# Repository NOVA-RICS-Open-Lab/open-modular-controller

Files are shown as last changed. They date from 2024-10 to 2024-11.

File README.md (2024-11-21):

<div  align="center"> 

# Open Modular Controller for Automation Technologies




[Joao Potier](https://pt.linkedin.com/in/jo%C3%A3o-potier-5b1301228?trk=public_profile_samename-profile)<sup>1</sup>, 
[Miguel Arvana](https://scholar.google.com/citations?user=UBvr388AAAAJ&hl=pt-PT)<sup>1</sup>,
[Leandro Filipe](https://scholar.google.pt/citations?user=SoIohJwAAAAJ&hl=en)<sup>1</sup>,
[Fabio M-Oliveira](https://www.researchgate.net/profile/Fabio-M-Oliveira)<sup>1</sup>,
[Andre Rocha](https://scholar.google.pt/citations?user=k1GIyqcAAAAJ&hl=pt-PT)<sup>1</sup>,
[Jose Barata](https://scholar.google.pt/citations?user=4G8tKCsAAAAJ&hl=en)<sup>1</sup>

<sup>1</sup> **NOVA School of Science and Technology, Center of Technology and Systems (UNINOVA-CTS)**,
and Associated Lab of Intelligent Systems (LASI), NOVA University
Lisbon, 2829-516 Lisbon, Portugal

<table>
  <tr>
    <td style="vertical-align: top;">
      This work proposes the development of a controller, with modularity and flexibility as the core ideas, that allows for the integration of open-source standards like the proprietary technologies used in emergent factories and automation technologies. The implementation of this architecture led to the development of a prototype modular industrial controller that is, on average, a quarter of the cost of the new generation of industrial controllers. The developed controller was tested and validated using some educational kits.
    </td>
    <td style="vertical-align: top;">
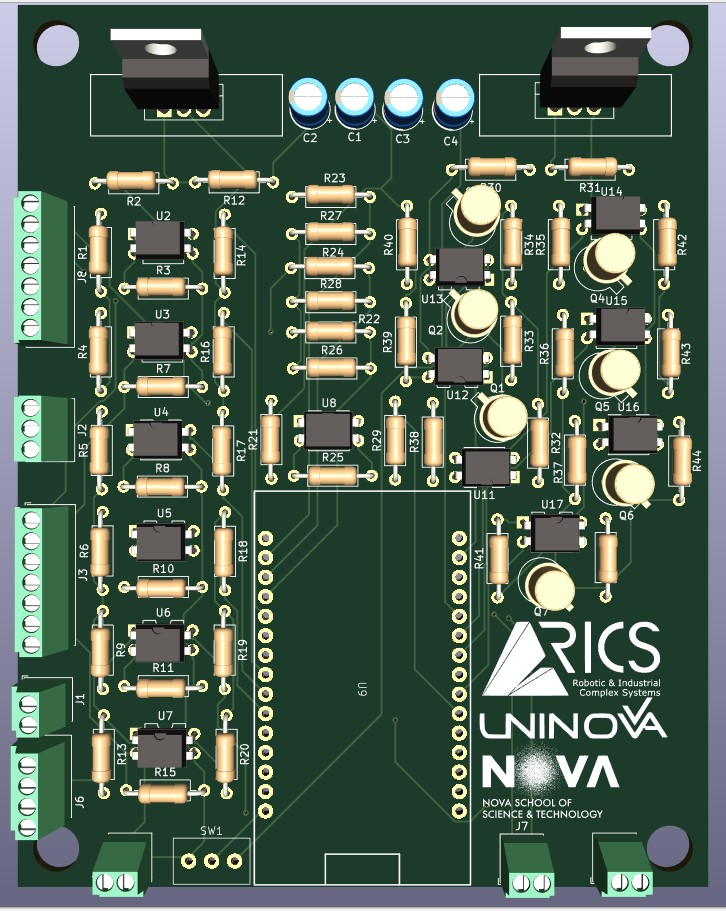
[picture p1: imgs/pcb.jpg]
pcb
      
    </td>
  </tr>
</table>

</div>

## <div align="center">Get Started</div>
Follow these steps to create your own functional PCB and set up the ESP:

1. **Order or Print the PCB**
   - Locate the PCB Gerber files in the repository at [Gerber.zip](./docs/pcb/Gerbers.zip).
   - Upload this zip file to a PCB manufacturer (such as [JLCPCB](https://jlcpcb.com/) or a similar service) to order the PCB, or print it yourself if you have access to the necessary equipment.

2. **Gather Components**
   - Obtain all components listed in [materials.xlsx](./docs/pcb/materials.xlsx).
   - Ensure that you source parts that match the specifications provided for optimal functionality.

3. **Assemble the PCB**
   - Carefully assemble the PCB following the schematic available [here](./imgs/schematic.png).
   - Use appropriate tools and ensure correct orientation and placement of components.

4. **Test the PCB**
   - Before powering up, inspect the PCB for short circuits, weak solder joints, or other assembly issues.
   - Use a multimeter to verify connections and confirm proper voltage levels across components.

5. **Program and Test the ESP**
   - Program the ESP with the provided code, following the libraries in the [src/libs](./src/libs) folder. Test your assembled controller and code setup with this short [example](./src/protoboardValid.ino).
   - Test each pin individually to verify its input and output behavior. The ESP should handle a standard 24V input/output.

If all tests pass, congratulations! Your board is now ready for operation.

---

### Usage instructions
Once your PCB and ESP setup is complete, you can begin using the device. The ESP manages the input and output for each control pin, with a standard operating voltage of 24V. Please note:

- **Control Limitations**: These pins are designed for control signals only. Avoid applying high current loads to prevent damage.
- **Testing & Example Code**: Refer to the [tests](./tests/) folder for use case examples and tests that helped validate board functionality. This includes the protoboard validation, Wi-Fi connection, Web Server and IP connection.

Follow these guidelines, and your project should operate as expected!

---

### Project Structure
For you to better understand this repository organization here is a quick overview of its structure and where to find what you might be looking for:
```
open-modular-controller
├── docs                # documentation assets
│   ├── circuits            # digital and analog circuit study
│   ├── pcb                 # pcb assets and materials
│   └── thesis.pdf          # master thesis
├── imgs                # images from this project
├── src                 # evaluation code
│   ├── libs                # developed libraries
│   └── protoboardValid.ino         # validation circuit
└── tests               # use case example scripts
```

## <div align="center">Documentation</div>
The [docs](./docs/) directory contains extensive resources, including schematics, materials lists, and PCB files, as well as the original master’s dissertation that inspired this project. Explore this folder to access all necessary assets for building, assembling, and understanding the hardware.

The presented use case for the protoboard validation showcases an asynchronous Web Server, providing a more stable connection than a synchronous web server. A toggle switch sends an HTTP request to the Processing Unit Module, initiating movement in the Kit. When the switch is active, it enables continuous operation of the Kit's process. Upon deactivation, the Industrial Kit halts movement at the start of the next cycle.

> **Note**: The resistors R1, R4, R5, R6, R9, R13, and R21, **originally specified as 1.1K, have been updated to 33K** in both the schematic and materials list. This adjustment was made due to performance issues with certain conveyor belts that were not functional with the previous resistor values. Documenting this change is essential for any future debugging.

## <div align="center">Contribution Guidelines</div>
NOVA RICS Open Lab open source, and we welcome contributions from the community! See the [Contribution](CONTRIBUTING.md) guide for more information on the development workflow and the internals of the wandb library. For project related bugs and feature requests, visit [GitHub Issues](https://github.com/NOVA-RICS-Open-Lab/open-modular-controller/issues) or contact novaricsopenlab@gmail.com

## <div align="center">Citation</div>
If you use or intend to build on top of  the work in this repo, please consider citing our project:
```bibtex
@inproceedings{10639979,
  author={Potier, João and Arvana, Miguel and Filipe, Leandro and M-Oliveira, Fabio and Rocha, Andre Dionisio and Barata, Jose},
  booktitle={2024 IEEE 7th International Conference on Industrial Cyber-Physical Systems (ICPS)}, 
  title={Development of an Open, Modular Controller for Training in Emergent Automation Technologies}, 
  year={2024},
  doi={10.1109/ICPS59941.2024.10639979}
}
```

## <div align="center">License</div>
This repository is released under the MIT License. Please see the [LICENSE](LICENSE) file for more details.

## <div align="center">Contacts</div>
For any questions regarding this or any other project please contact us at novaricsopenlab@gmail.com or enroll in our [Discussion Forum](https://github.com/NOVA-RICS-Open-Lab/open-modular-controller/discussions) for sharing your ideas and sharing projects.

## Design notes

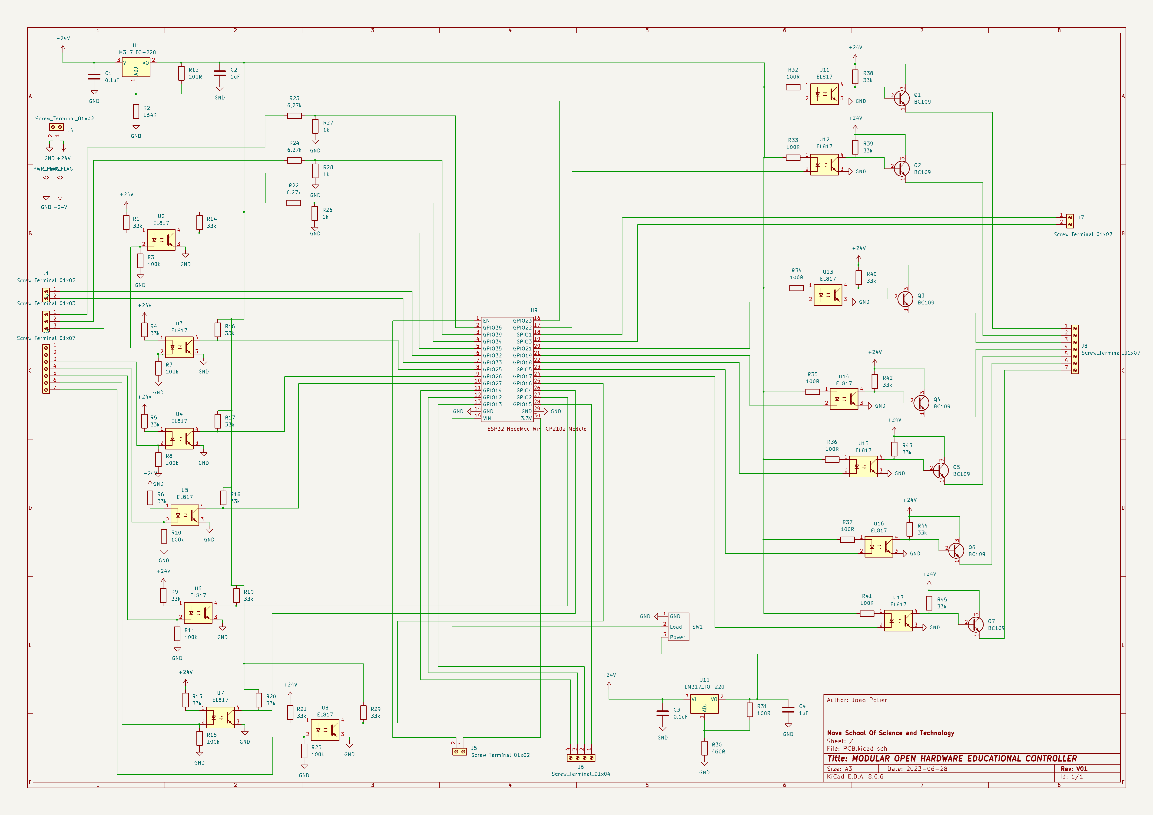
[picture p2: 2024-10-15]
imgs/schematic.png

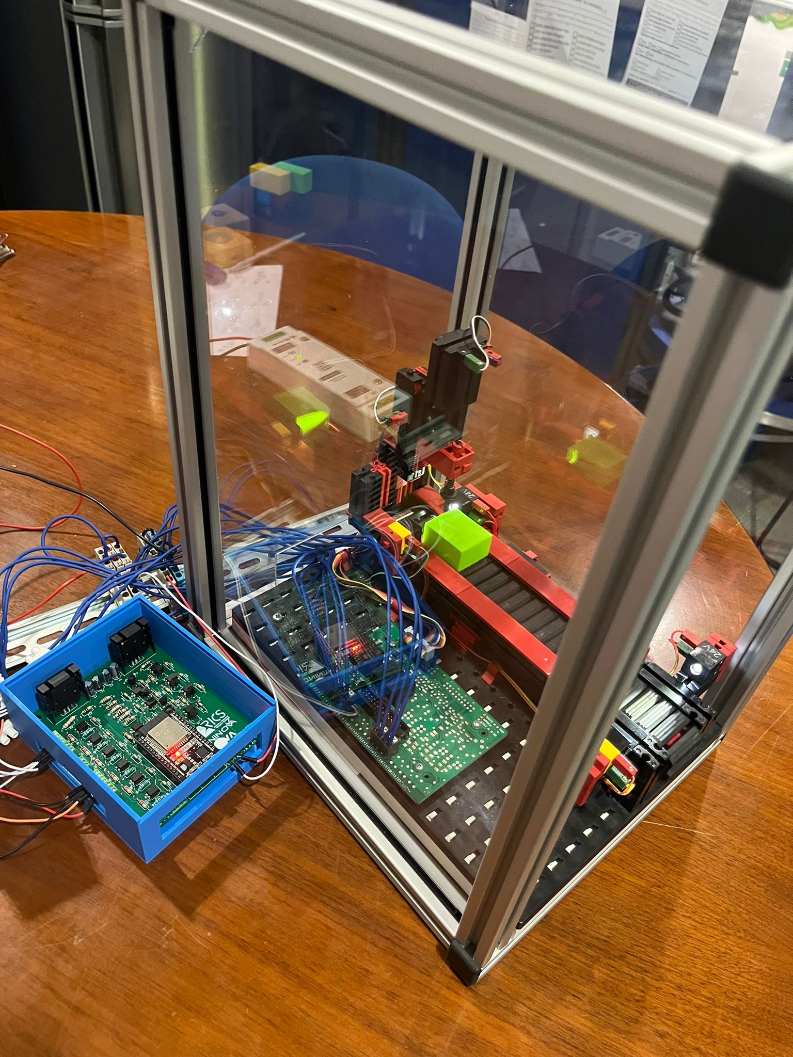
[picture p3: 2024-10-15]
imgs/use_case.jpg

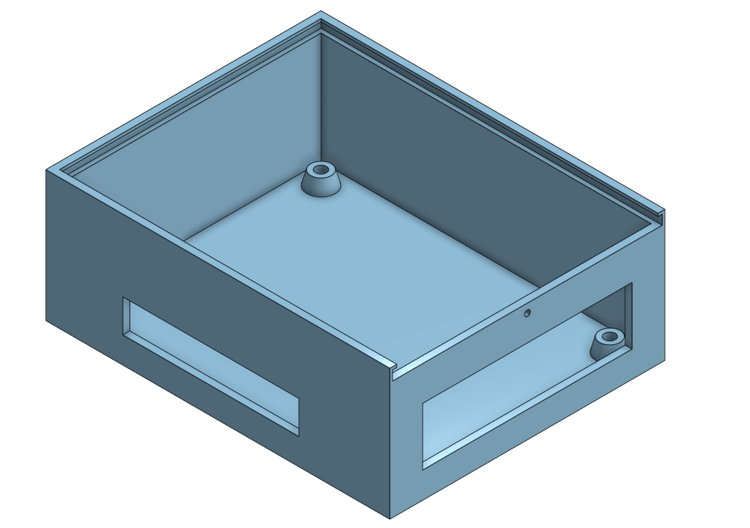
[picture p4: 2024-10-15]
imgs/3d_box.png

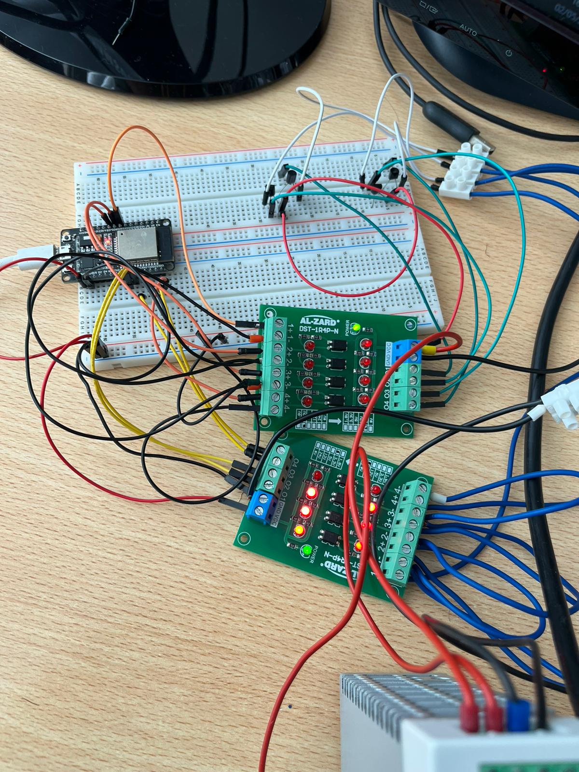
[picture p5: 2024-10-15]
imgs/sensors_actuators.jpg

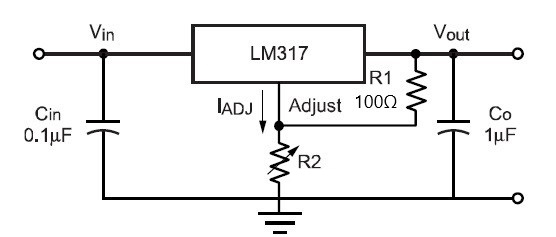
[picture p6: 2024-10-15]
docs/circuits/LM317Circuit.jpg

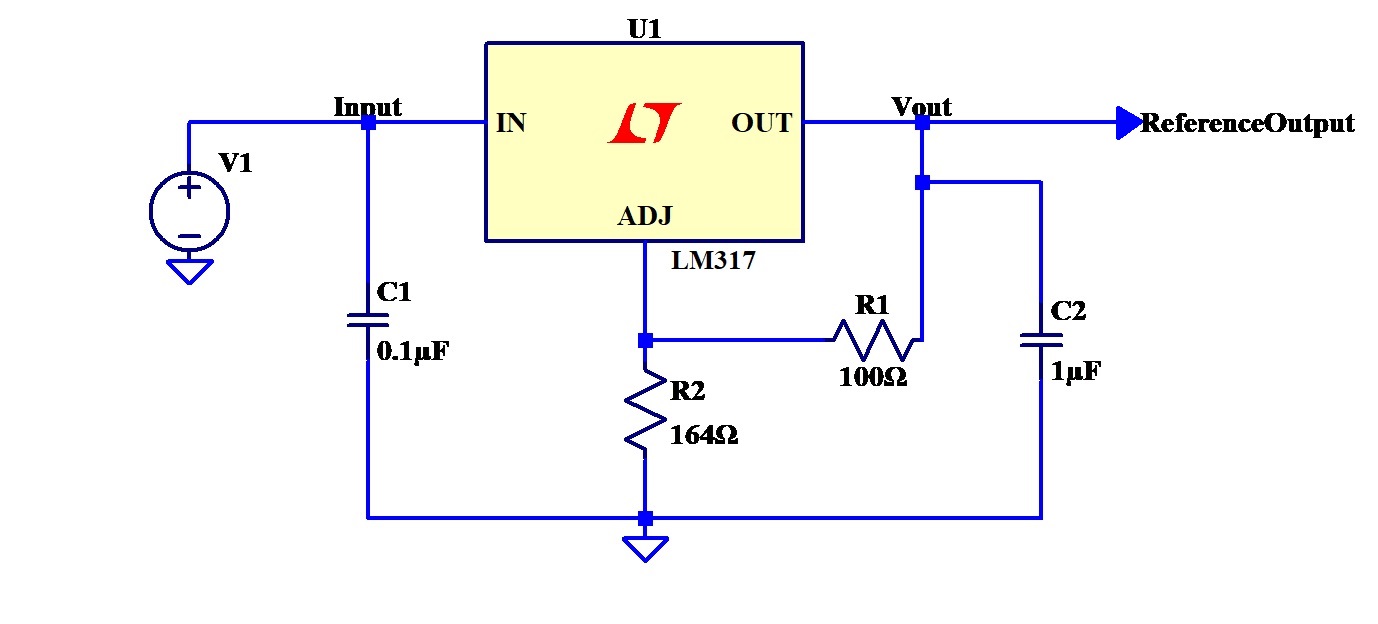
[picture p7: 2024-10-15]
docs/circuits/LM317Circuit_33V.jpg

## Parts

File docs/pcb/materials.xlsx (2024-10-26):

Quantity | Value | LibPart | Footprint | Link | Notes
2 | 1uF | Capacitor | Capacitor_THT:CP_Radial_D5.0mm_P2.00mm | https://mauser.pt/catalog/product_info.php?products_id=004-0013
2 | 0,1uF | Capacitor | Capacitor_THT:CP_Radial_D5.0mm_P2.00mm | https://mauser.pt/catalog/product_info.php?products_id=004-0001
0 | 1,1k | Resistor | Resistor_THT:R_Axial_DIN0207_L6.3mm_D2.5mm_P10.16mm_Horizontal | https://mauser.pt/catalog/product_info.php?products_id=104-7459 | Não existem resistências destas. As de 1,2K funcionam/// Foram subestituidas por 33K
7 | 100k | Resistor | Resistor_THT:R_Axial_DIN0207_L6.3mm_D2.5mm_P10.16mm_Horizontal | https://mauser.pt/catalog/product_info.php?products_id=104-7060
9 | 100R | Resistor | Resistor_THT:R_Axial_DIN0207_L6.3mm_D2.5mm_P10.16mm_Horizontal | https://mauser.pt/catalog/product_info.php?products_id=104-7358
1 | 164R | Resistor | Resistor_THT:R_Axial_DIN0207_L6.3mm_D2.5mm_P10.16mm_Horizontal | https://mauser.pt/catalog/product_info.php?products_id=104-7478 | Não existem resistências destas. As de 150 funcionam
3 | 1k | Resistor | Resistor_THT:R_Axial_DIN0207_L6.3mm_D2.5mm_P10.16mm_Horizontal | https://mauser.pt/catalog/product_info.php?products_id=104-7597
21 | 33k | Resistor | Resistor_THT:R_Axial_DIN0207_L6.3mm_D2.5mm_P10.16mm_Horizontal | https://mauser.pt/catalog/product_info.php?products_id=104-7794
1 | 460R | Resistor | Resistor_THT:R_Axial_DIN0207_L6.3mm_D2.5mm_P10.16mm_Horizontal |  | Não existem resistências destas. As de 470 funcionam
3 | 6,27k | Resistor | Resistor_THT:R_Axial_DIN0207_L6.3mm_D2.5mm_P10.16mm_Horizontal | https://mauser.pt/catalog/product_info.php?products_id=104-7668 | Não existem resistências destas. As de 6,2K funcionam
7 | BC547 | Transistor_BJT | Package_TO_SOT_THT:TO-18-3 | https://mauser.pt/catalog/product_info.php?products_id=002-0243
14 | EL817 | Isolator | Package_DIP:DIP-4_W7.62mm | https://mauser.pt/catalog/product_info.php?products_id=002-1805
2 | LM317_TO-220 | Regulator_Linear | Package_TO_SOT_THT:TO-220-3_Vertical | https://mauser.pt/catalog/product_info.php?products_id=001-9061
3 | Screw_Terminal_01x02 | Connector | TerminalBlock_Phoenix:TerminalBlock_Phoenix_MPT-0,5-2-2.54_1x02_P2.54mm_Horizontal | https://mauser.pt/catalog/product_info.php?products_id=011-1612
1 | Screw_Terminal_01x03 | Connector | TerminalBlock_Phoenix:TerminalBlock_Phoenix_MPT-0,5-3-2.54_1x03_P2.54mm_Horizontal | https://mauser.pt/catalog/product_info.php?products_id=011-2824
1 | Screw_Terminal_01x04 | Connector | TerminalBlock_Phoenix:TerminalBlock_Phoenix_MPT-0,5-4-2.54_1x04_P2.54mm_Horizontal | https://mauser.pt/catalog/product_info.php?products_id=011-2825
2 | Screw_Terminal_01x07 | Connector | TerminalBlock_Phoenix:TerminalBlock_Phoenix_MPT-0,5-7-2.54_1x07_P2.54mm_Horizontal |  | Combinar um bloco de 3 com um bloco de 4

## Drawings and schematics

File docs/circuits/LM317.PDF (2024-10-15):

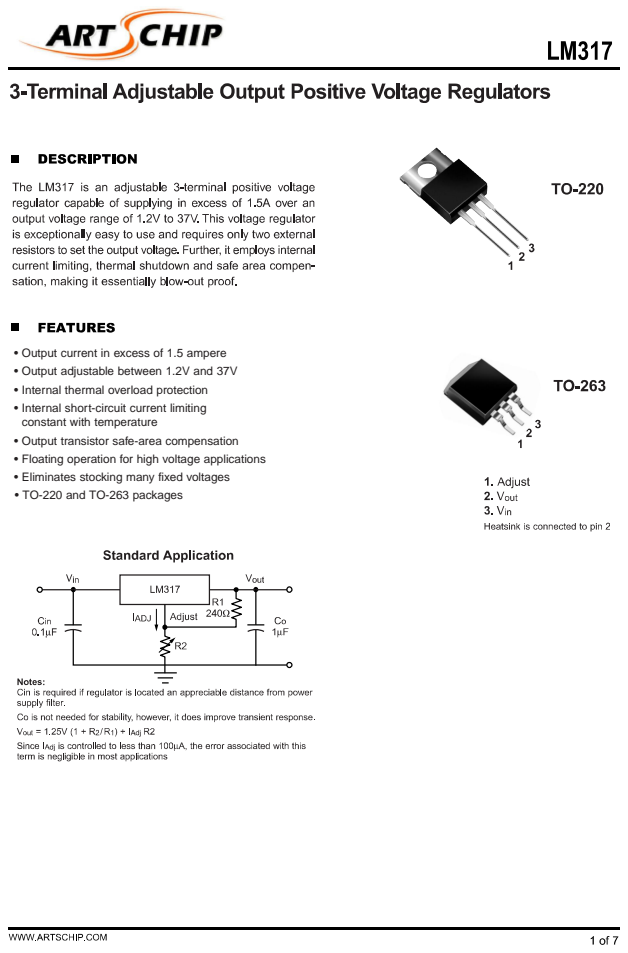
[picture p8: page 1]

• Output current in excess of 1.5 ampere
• Output adjustable between 1.2V and 37V
• Internal thermal overload protection
• Internal short-circuit current limiting
constant with temperature
• Output transistor safe-area compensation
• Floating operation for high voltage applications
• Eliminates stocking many fixed voltages
• TO-220 and TO-263 packages

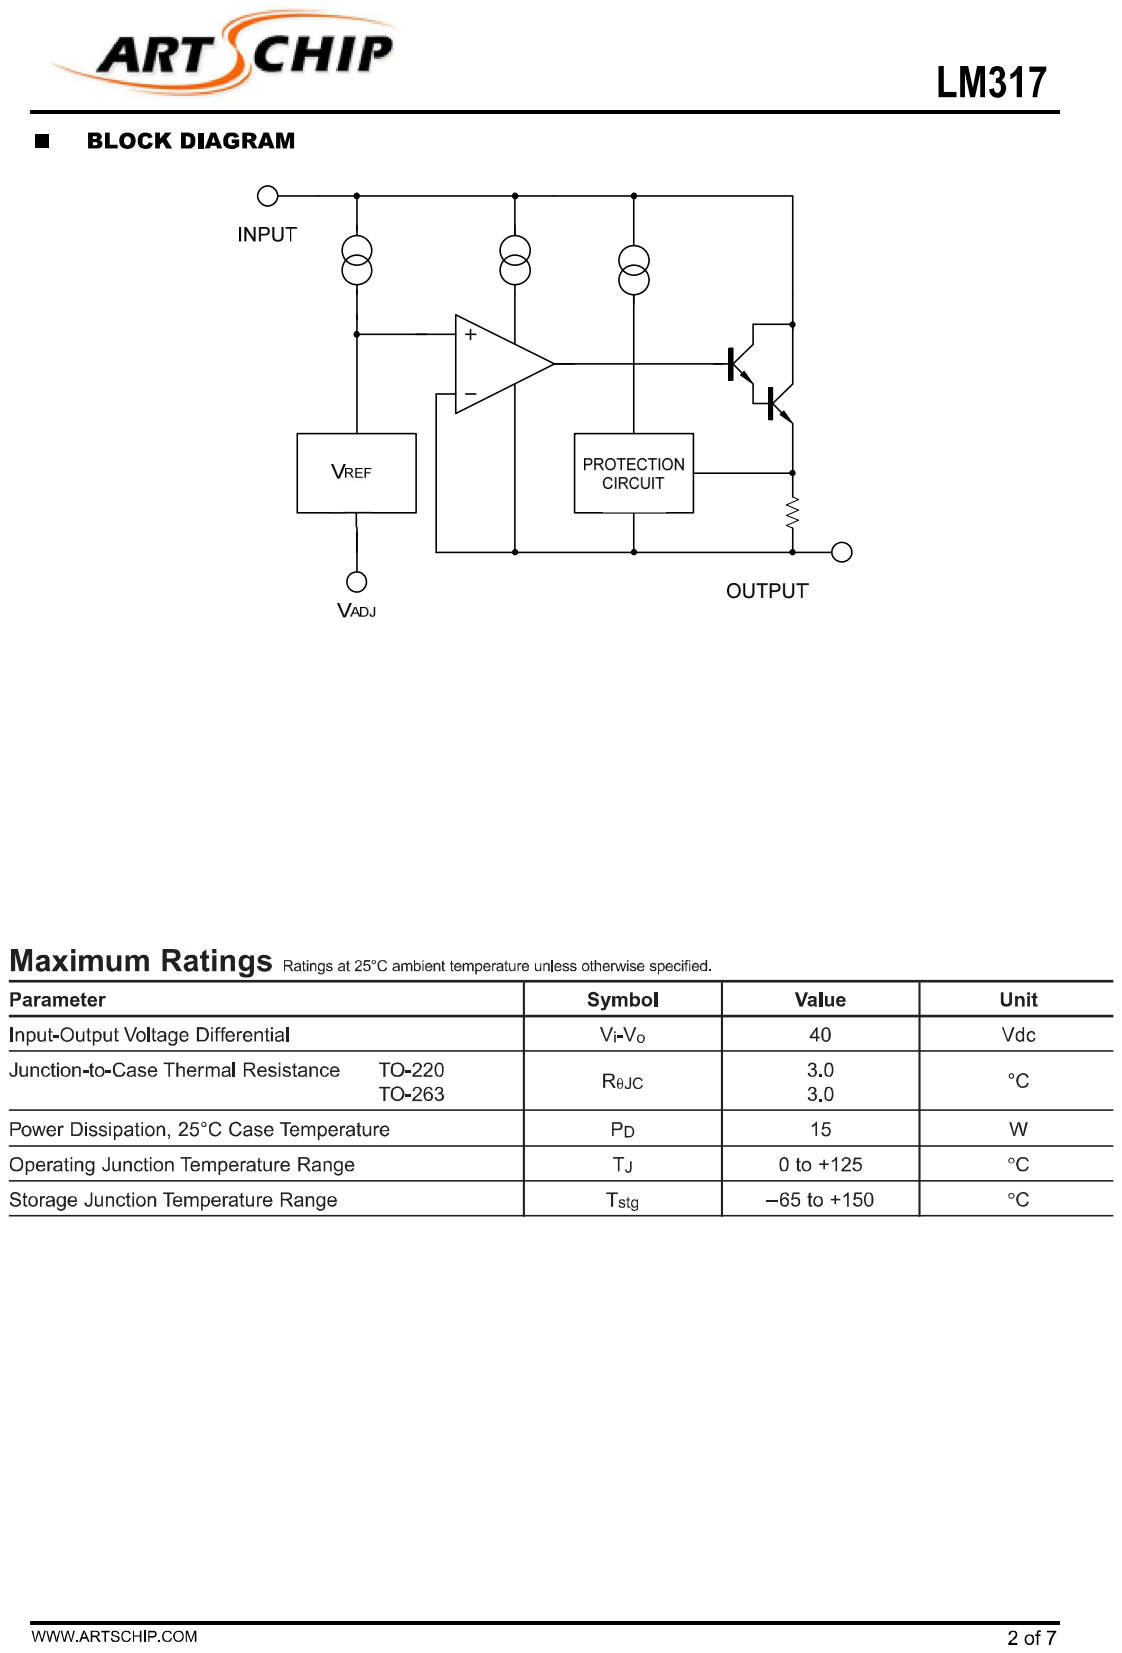
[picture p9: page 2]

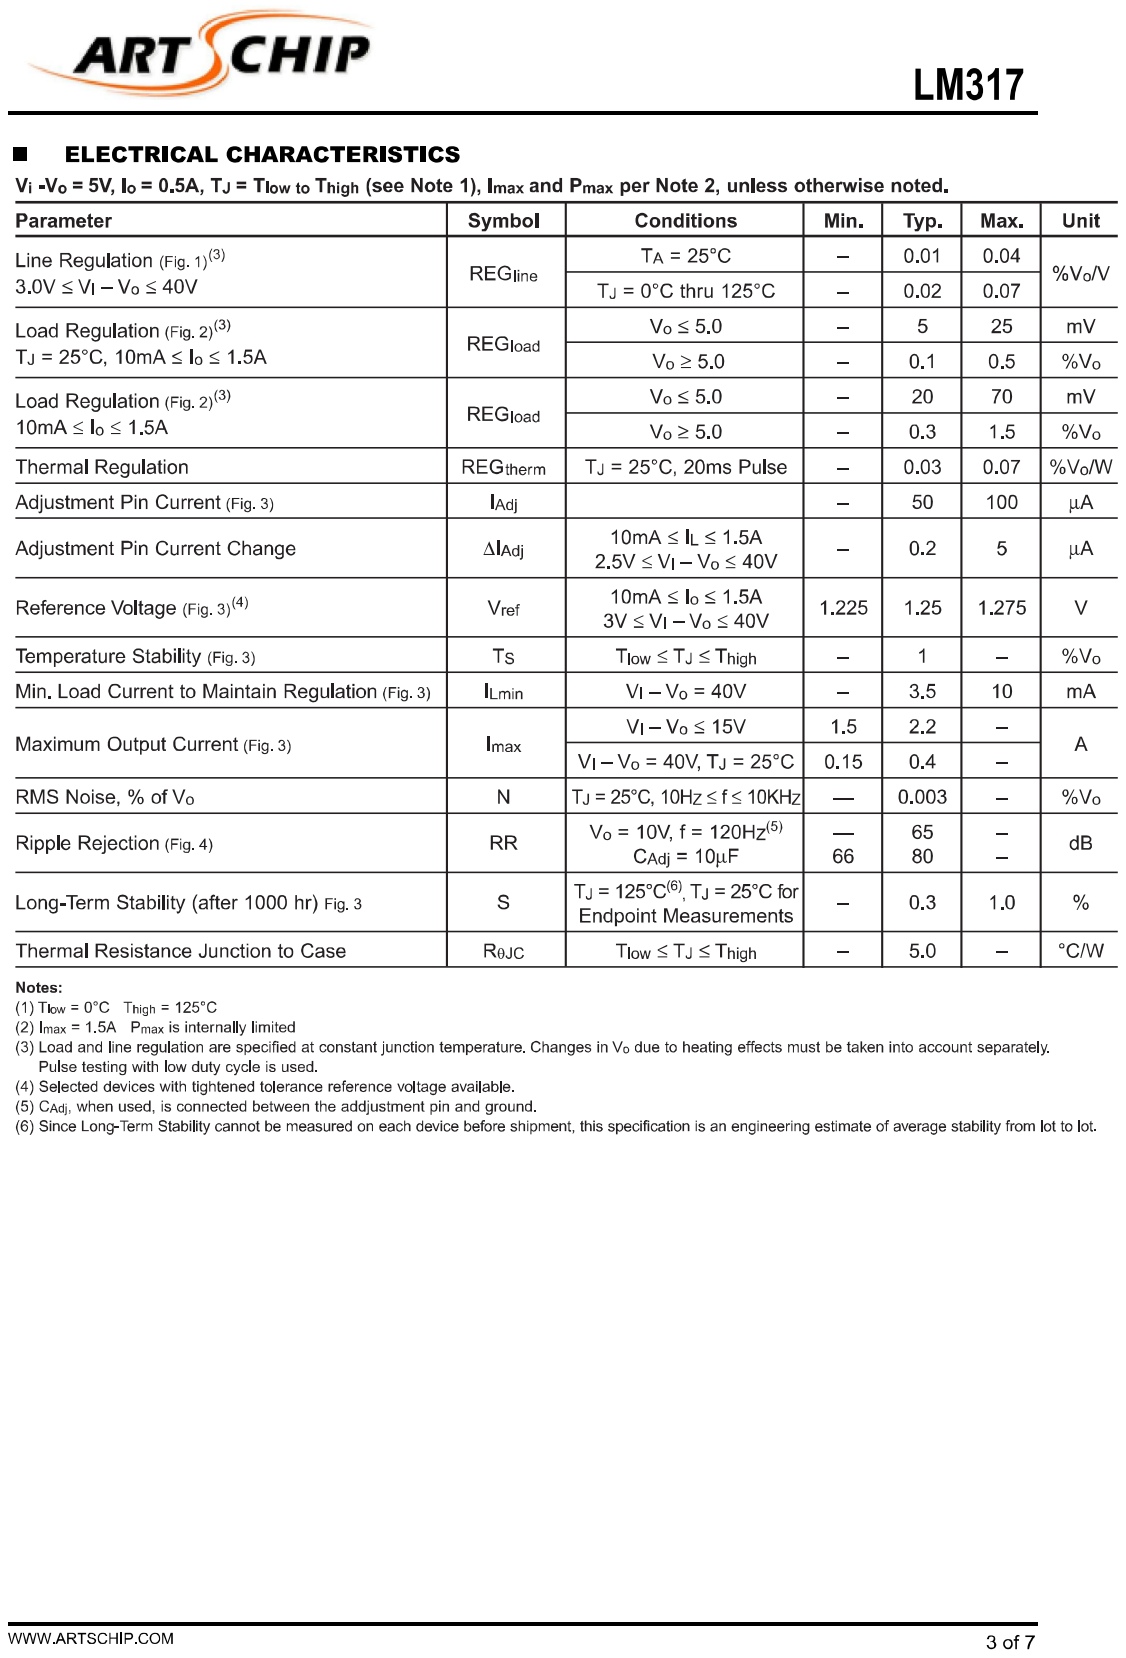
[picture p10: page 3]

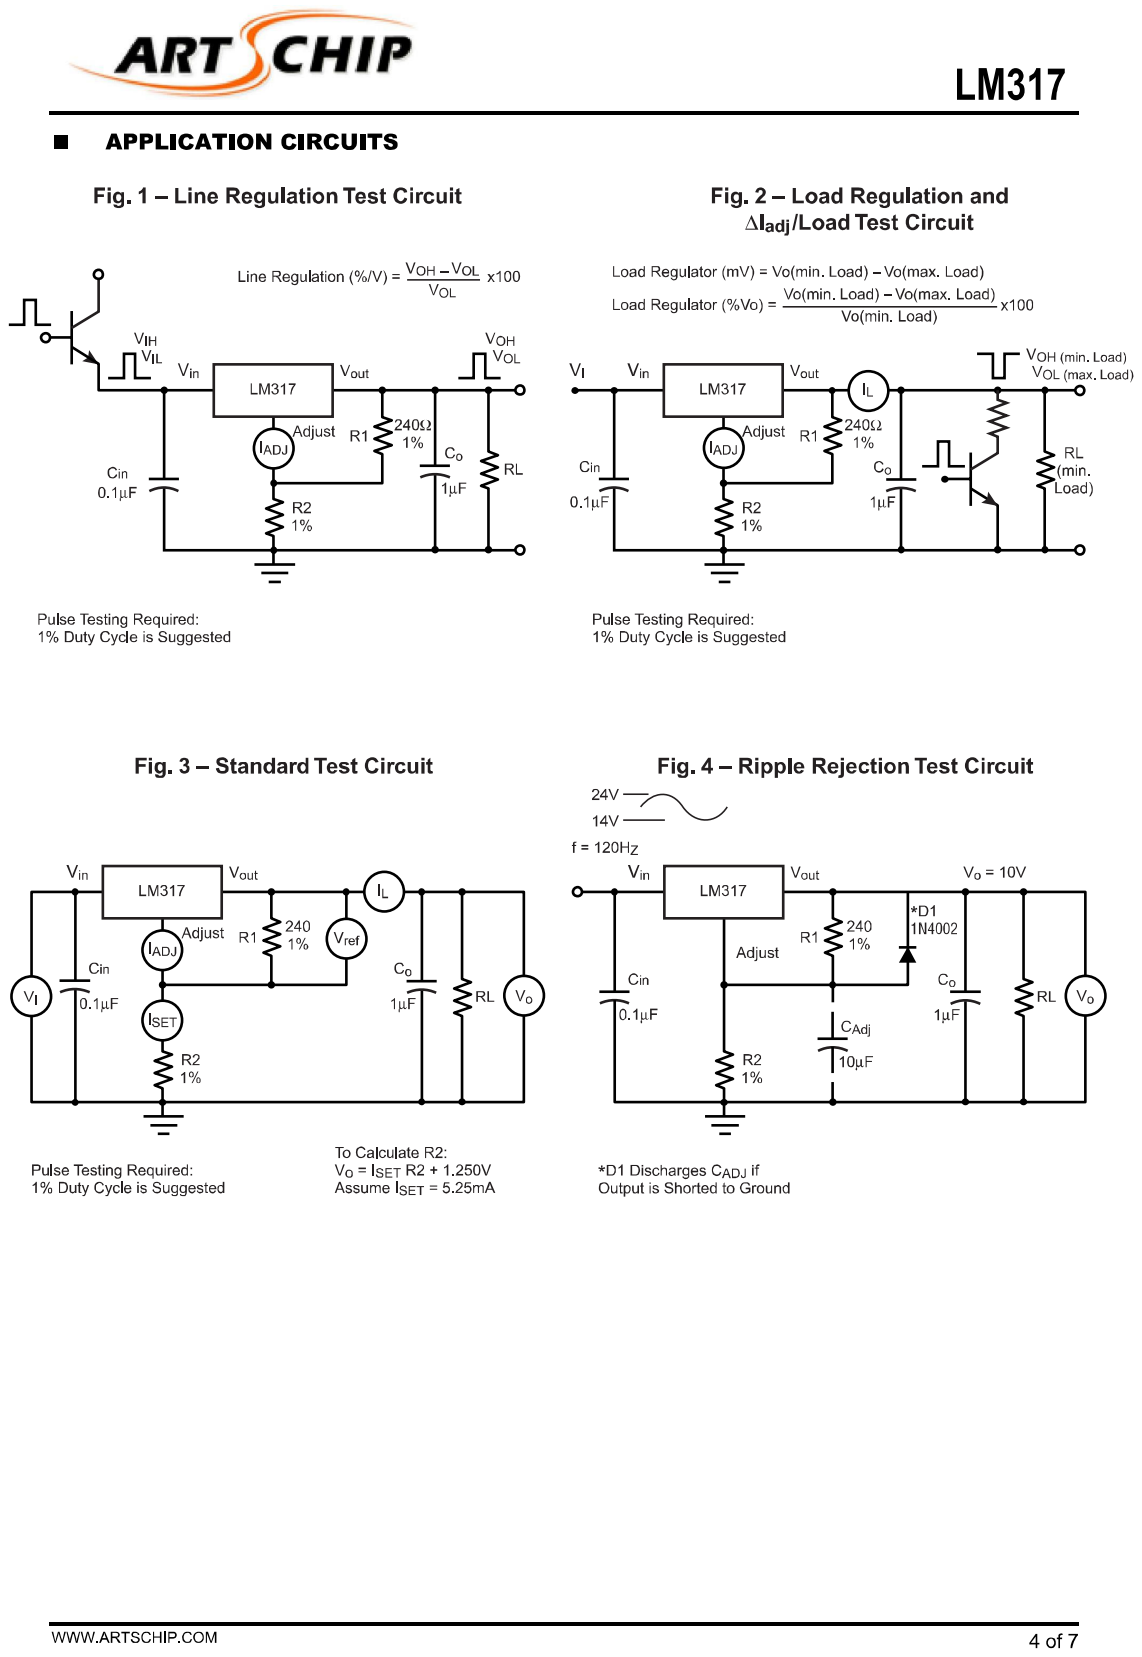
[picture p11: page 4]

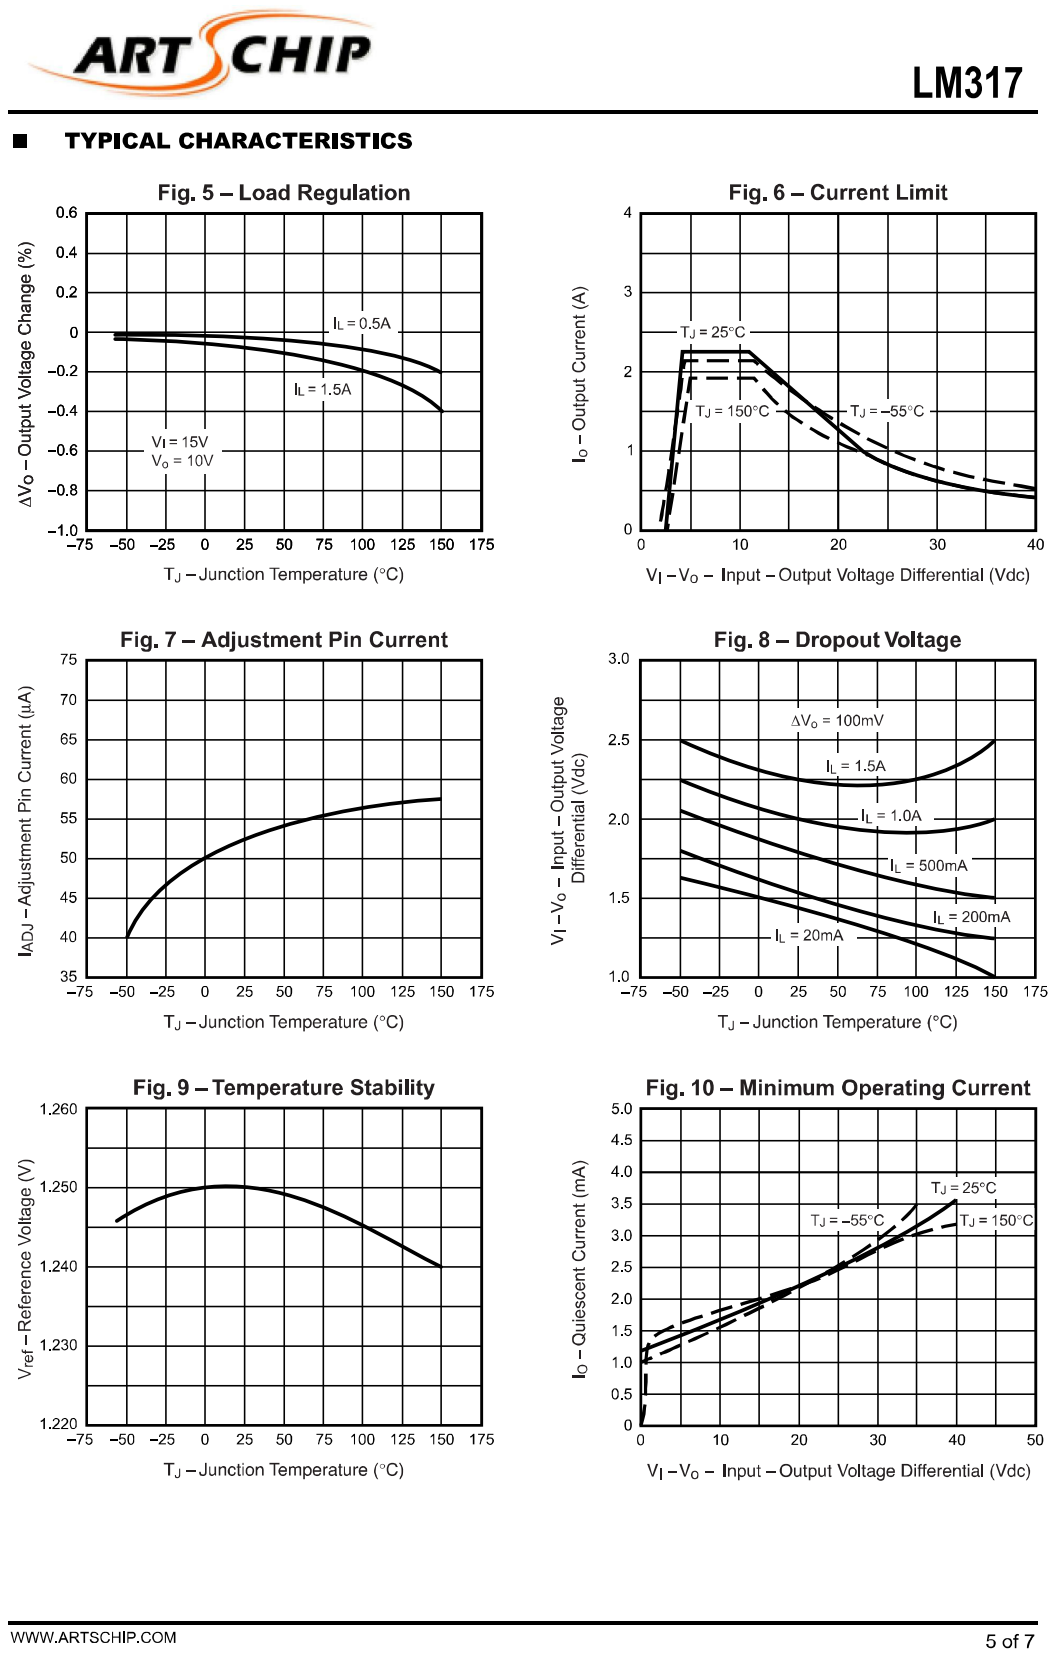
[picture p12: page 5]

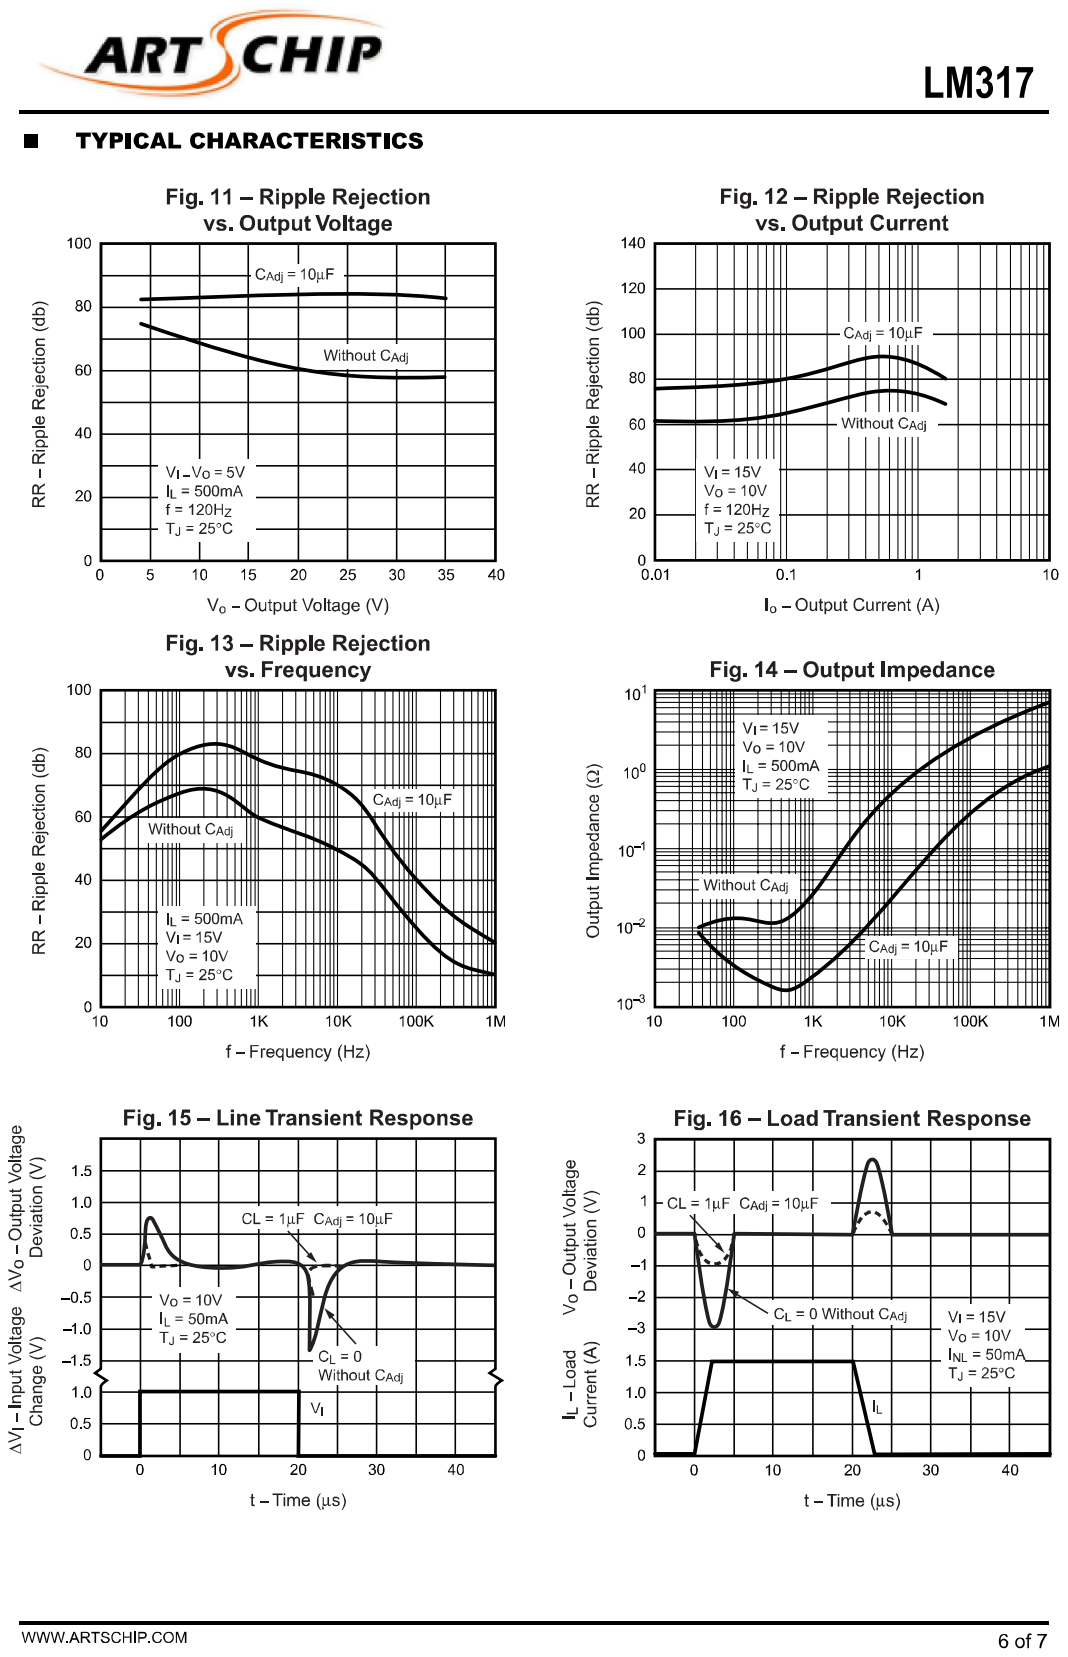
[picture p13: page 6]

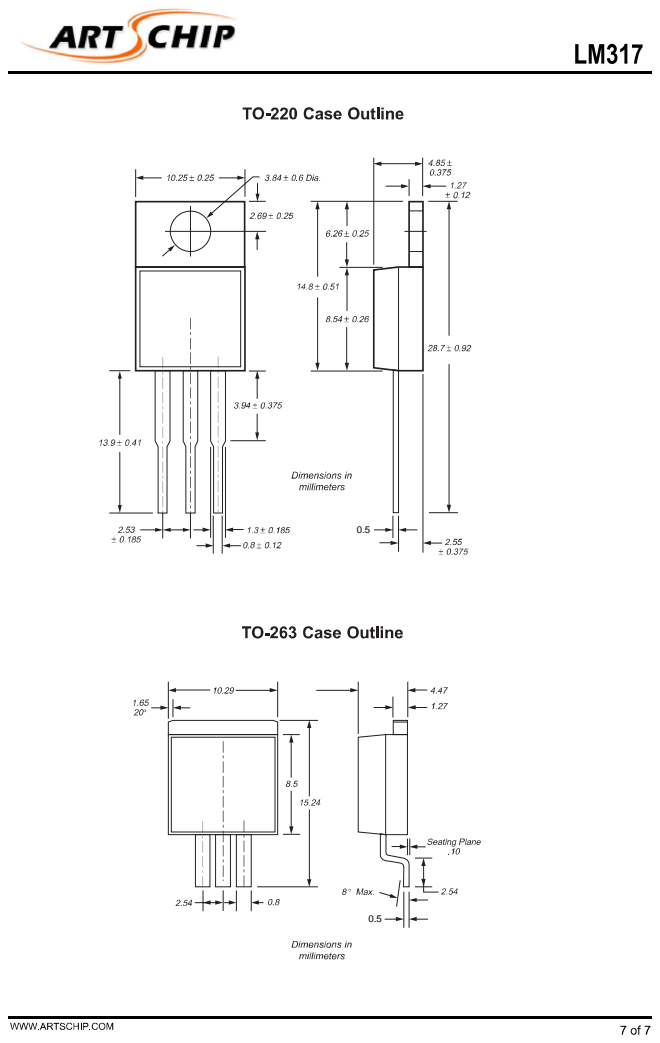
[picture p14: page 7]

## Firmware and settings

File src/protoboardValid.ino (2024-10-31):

#include "protoboardLib.h"

Node node = Node();
int in1, in2;

void setup() {
  node.initDigitalInput("I6");
  Serial.begin(9600);
}


void loop() {
  in2 = node.readDigitalPort("I6");
  Serial.write("->");

  if(in2 == LOW){
    Serial.write("Sensor 2 not active\n");
  }

  if(in2 == HIGH){
    Serial.write("Sensor 2 is active\n");
      
  } 
  delay(5000);
}

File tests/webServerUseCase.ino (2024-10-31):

#include <WiFi.h>
#include <AsyncTCP.h>
#include <ESPAsyncWebServer.h>
#include "protoboardLib.h"
#include "useCaseKitLib.h"

// Replace with your network credentials
const char* ssid = "YOUR-SSID";
const char* password = "YOUR-PASSWORD";

const char* PARAM_INPUT_1 = "output";
const char* PARAM_INPUT_2 = "state";
const char* STATE = "OFF";

Node node = Node();
int in1, in2, in3, in4;

// Industrial Kit Movement Sequence
void machineExecution() {
  while(STATE != "OFF"){
      
    stopPunching();
    stopConveyor();

    // WAIT for a product in the starting position
    while(readEntrySensor() != LOW){  
      delay(100);
    }

    Serial.write("Product received\n");
    moveConveyorFront();

    // WAIT for a product in the Punching station
    while(readWorkStationSensor() != LOW){  
      delay(100);
    }

    stopConveyor();
    Serial.write("Product in station\n");

    // EXECUTE Punching routine
    while(readMachineLowSensor() != HIGH){
      movePunchingDown();
    }

    stopPunching();
    delay(1500);

    while(readMachineHighSensor() != HIGH){
      movePunchingUp();
    }

    stopPunching();

    // WAIT for a product in the starting position
    while(readEntrySensor() != LOW){  
      moveConveyorBack();
    }

    stopConveyor();
    Serial.write("Process finished\n");

  }
  return;
}

// Create AsyncWebServer object on port 80
AsyncWebServer server(80);

const char index_html[] PROGMEM = R"rawliteral(
<!DOCTYPE HTML><html>
<head>
  <title>ESP Web Server</title>
  <meta name="viewport" content="width=device-width, initial-scale=1">
  <link rel="icon" href="data:,">
  <style>
    html {font-family: Arial; display: inline-block; text-align: center;}
    h2 {font-size: 3.0rem;}
    p {font-size: 3.0rem;}
    body {max-width: 600px; margin:0px auto; padding-bottom: 25px;}
    .switch {position: relative; display: inline-block; width: 120px; height: 68px} 
    .switch input {display: none}
    .slider {position: absolute; top: 0; left: 0; right: 0; bottom: 0; background-color: #ccc; border-radius: 6px}
    .slider:before {position: absolute; content: ""; height: 52px; width: 52px; left: 8px; bottom: 8px; background-color: #fff; -webkit-transition: .4s; transition: .4s; border-radius: 3px}
    input:checked+.slider {background-color: #b30000}
    input:checked+.slider:before {-webkit-transform: translateX(52px); -ms-transform: translateX(52px); transform: translateX(52px)}
    .center-image {
      display: flex;
      justify-content: center;
      align-items: center;
    }
  </style>
</head>
<body>
  <h2>ESP Web Server</h2>
  %BUTTONPLACEHOLDER%
<script>function toggleCheckbox(element) {
  var xhr = new XMLHttpRequest();
  if(element.checked){ xhr.open("GET", "/update?output="+element.id+"&state=1", true); }
  else { xhr.open("GET", "/update?output="+element.id+"&state=0", true); }
  xhr.send();
}
</script>
</body>
<body2>
    <div class="center-image">
      <a data-flickr-embed="true" href="https://www.flickr.com/photos/199239236@N04/53217524602/in/dateposted-public/" title="kit">
        <img src="https://live.staticflickr.com/65535/53217524602_f9231e8afb.jpg" width="500" height="364" alt="kit"/>//</a>
      <script async src="//embedr.flickr.com/assets/client-code.js" charset="utf-8"></script>
    </div>
</body2>
<index>
    <div class="center-image">
      <img src="https://upload.wikimedia.org/wikipedia/commons/c/ca/Novologofct2021.png" alt="Novologofct2021.png" width="200" height="146">
      <img src="https://www.uninova.pt/sites/default/files/styles/logotipo/public/logo/logotipo_uninova_0.png?itok=XI5qW0Kv" alt="UNINOVA.png" width="200" height="60">
      <img src="https://static.wixstatic.com/media/56223c_983be1e886664ecebd19a66e1ab5e14b~mv2.png/v1/fill/w_190,h_99,al_c,q_85,usm_0.66_1.00_0.01,enc_auto/rics_image_red.png" alt="RICSLOGO.png" width="200" height="100">          
    </div>
</index>
</html>
)rawliteral";


String outputState(){
  if(STATE == "ON"){
    return "checked";
  }
  else {
    return "";
  }
}


// Replaces placeholder with button section in your web page
String processor(const String& var){
  //Serial.println(var);
  if(var == "BUTTONPLACEHOLDER"){
    String buttons = "";
    buttons += "<h4>Output - IndustrialKit</h4><label class=\"switch\"><input type=\"checkbox\" onchange=\"toggleCheckbox(this)\" id=\"2\" " + outputState() + "><span class=\"slider\"></span></label>";
    return buttons;
  }
  return String();
}


void setup(){
  // Serial port for debugging purposes
  Serial.begin(115200);

  node.initDigitalInput("I1");
  node.initDigitalInput("I2");
  node.initDigitalInput("I3");
  node.initDigitalInput("I4");
  node.initDigitalOutput("O1");
  node.initDigitalOutput("O2");
  node.initDigitalOutput("O3");
  node.initDigitalOutput("O4");

  // Connect to Wi-Fi
  WiFi.begin(ssid, password);
  while (WiFi.status() != WL_CONNECTED) {
    delay(1000);
    Serial.println("Connecting to WiFi..");
  }

  // Print ESP Local IP Address
  Serial.println(WiFi.localIP());

  // Route for root / web page
  server.on("/", HTTP_GET, [](AsyncWebServerRequest *request){
    request->send_P(200, "text/html", index_html, processor);
  });

  // Send a GET request to <ESP_IP>/update?output=<inputMessage1>&state=<inputMessage2>
  server.on("/update", HTTP_GET, [] (AsyncWebServerRequest *request) {
    String inputMessage1;
    String inputMessage2;

    // GET input1 value on <ESP_IP>/update?output=<inputMessage1>&state=<inputMessage2>
    if (request->hasParam(PARAM_INPUT_1) && request->hasParam(PARAM_INPUT_2)) {
      inputMessage1 = request->getParam(PARAM_INPUT_1)->value();
      inputMessage2 = request->getParam(PARAM_INPUT_2)->value();

      if(inputMessage2.toInt()==1){
        STATE="ON";
      }

      else{
        STATE="OFF";
      }

    }

    else {
      inputMessage1 = "No message sent";
      inputMessage2 = "No message sent";
    }

    Serial.print("MACHINE: ");
    Serial.print(inputMessage1);
    Serial.print(" - Set to: ");
    Serial.println(inputMessage2);
    request->send(200, "text/plain", "OK");
  });

  // Start server
  server.begin();
}


void loop() {
  machineExecution();
}

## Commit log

2024-10-15 project initial migration
    [PCB-B_Cu.gbl, PCB-B_Mask.gbs, PCB-B_Paste.gbp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]
2024-10-15 kicad update!
2024-10-15 Schematic and materials update
    [PCB.kicad_sch, materials.csv]
2024-10-26 project structure and docs
    [PCB-B_Cu.gbl, PCB-B_Mask.gbs, PCB-B_Paste.gbp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]
2024-10-31 repo restructure
    [PCB.kicad_sch, materials.xlsx]
2024-10-31 code fixes and improvements
    [protoboardValid.ino, rfidUseCase.ino, webServerUseCase.ino]

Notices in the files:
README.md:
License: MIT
